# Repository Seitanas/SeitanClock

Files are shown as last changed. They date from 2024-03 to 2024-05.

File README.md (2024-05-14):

# SeitanClock
NTP clock based on ESP 12F (ESP8266)

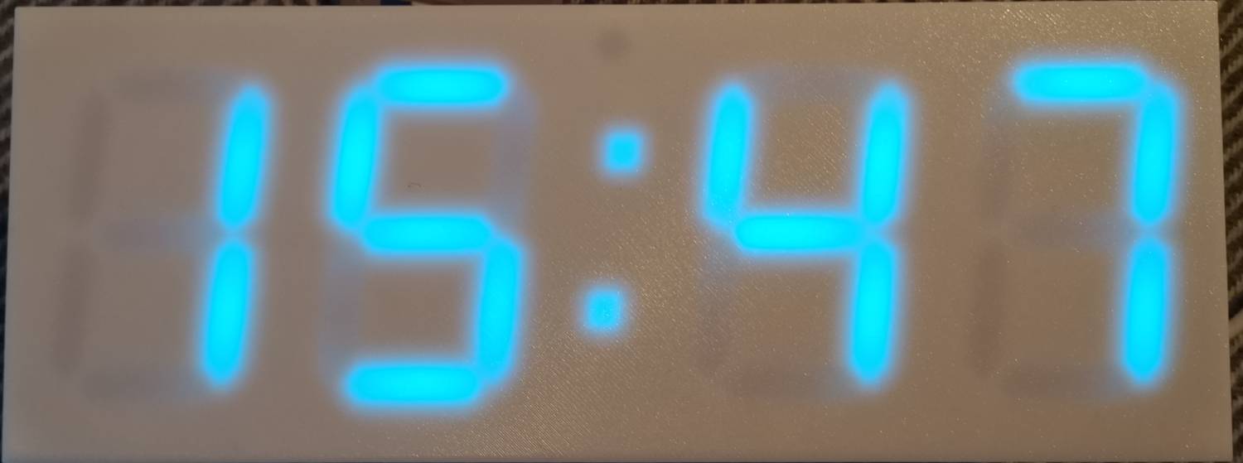
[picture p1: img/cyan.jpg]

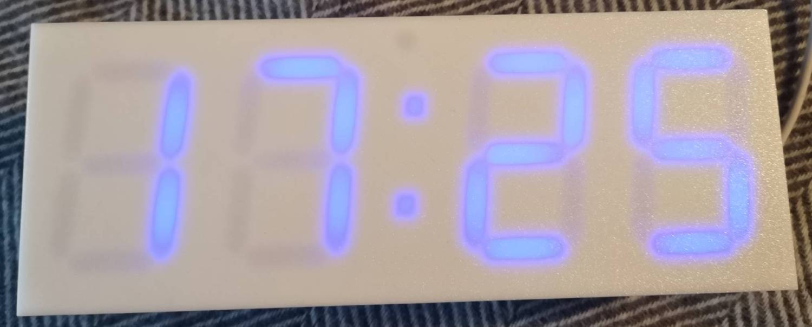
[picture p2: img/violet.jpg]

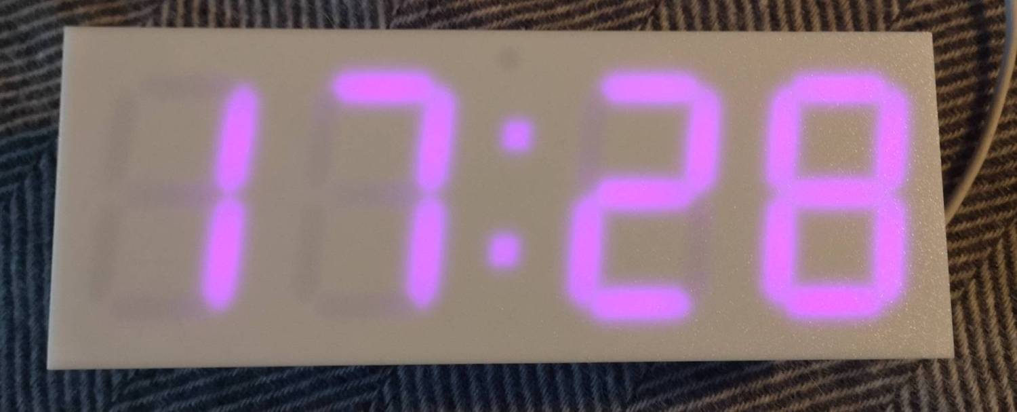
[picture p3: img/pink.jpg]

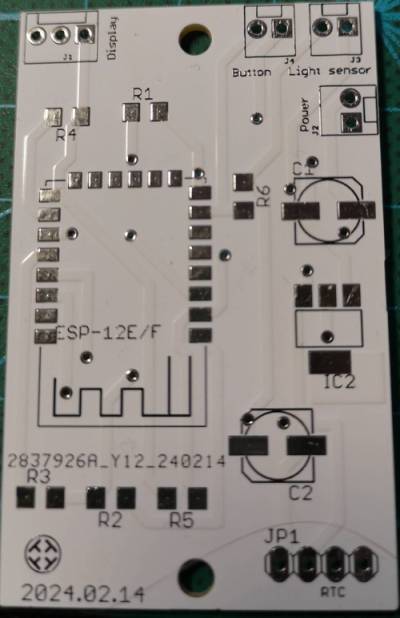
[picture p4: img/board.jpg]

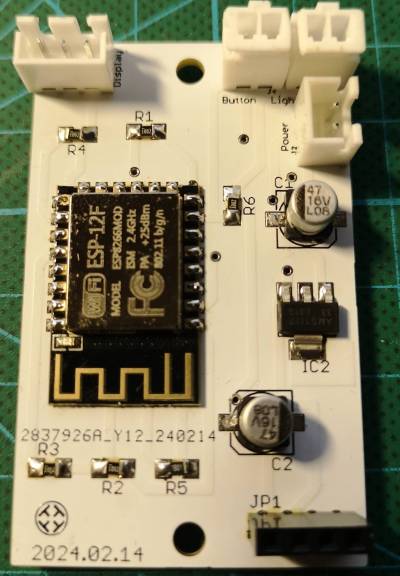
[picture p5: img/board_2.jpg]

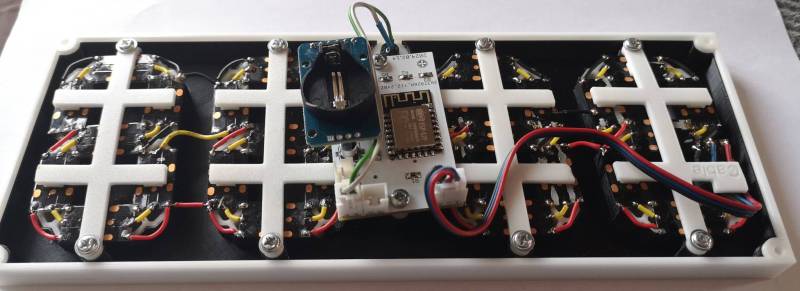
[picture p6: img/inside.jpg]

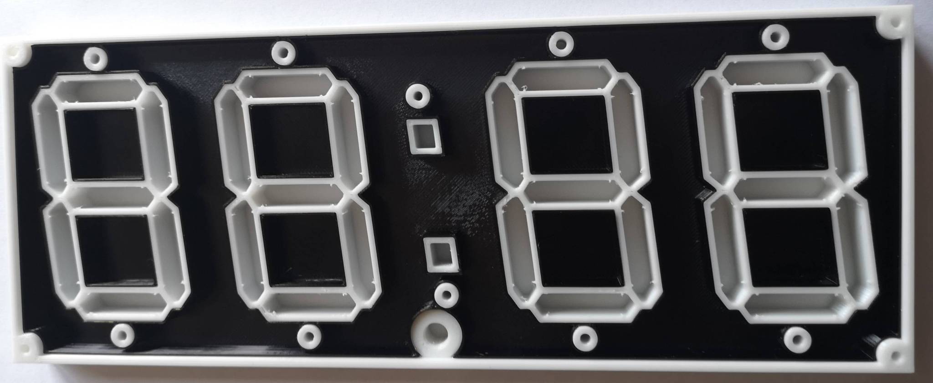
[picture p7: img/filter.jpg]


## Features
- 7 segment RGB display. Also suports stock i2c LED displays with HT16K33 driver.
- Clock synchronization via NTP over Wi-Fi.
- Updates display intensity (and color) according to day and nigh time.
- Displays date and temperature.
- Easy to use configuration portal.
- Firmware update via Wi-Fi.

## Setup mode
Clock enters setup mode at first boot (when no Wi-Fi configuration is present yet).
To enter setup mode manually, power-cycle clock while pressing the button down.
Display will show `StP` message.
In setup mode clock acts as Wi-Fi hot-spot. There will be new Wi-Fi network `SeitanClock-setup` available. Connect to it with default password `seitanclock`. Point your browser to `http://seitanclock-setup.local`. 
<u>Note</u>, that Android phones seems to lack MDNS support, so in case you are using Android phone, point your browser to IP instead: `http://192.168.4.1`. Default username for portal is `admin`, password `admin`.
Use setup portal to configure your clock. Save and reboot after.

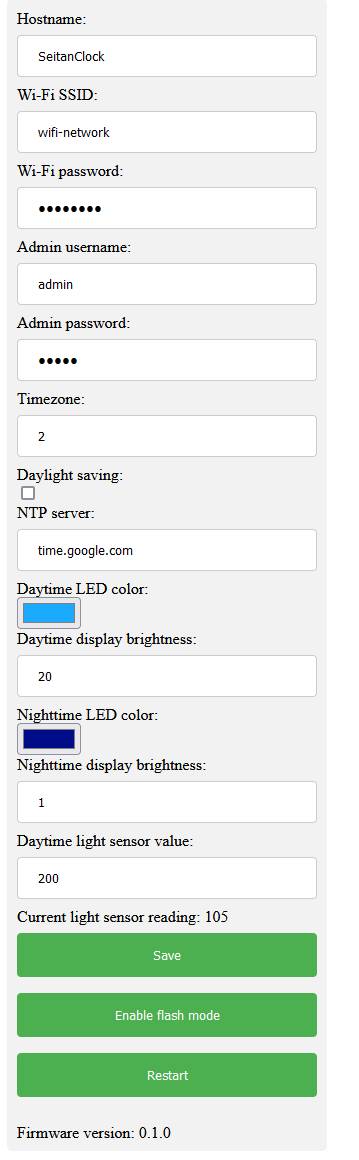
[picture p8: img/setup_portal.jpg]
Setup portal


## Flash mode
Clock has a built-in feature to update its firmware via Wi-Fi.
To get latest firmware:
- Get latest code release from https://github.com/Seitanas/SeitanClock
- Open it with Arduino IDE.
- Enter clock setup portal via `http://seitanclock.local`
- Push `Enable flash mode` button. Clock should display `FLA` message.
- Go to Arduino IDE -> Tools -> Port. Select `SeitanClock-flash.local` (or if you have changed clock host name, use `YOURHOSTNAME-flash.local`). You may need to wait for a moment for network port to appear.
<u>Note</u>, that clock and computer you are running Arduino IDE must reside in the same network segment.
- Select Sketch -> Upload.
- Wait for upgrade to finish. Clock will restart automatically. Firmware upgrade leaves clock configuration intact.

## Component list
- 1m WS2812B DC5V, 144 IP30 RGB LED tape.
- 1pc DS3231 RTC module.
- 1pc GL5506 LDR photosensitive resistor.
- 1pc ESP-12f module.
- 1pc 1.2K 1206 SMD resistor.
- 5pcs 10K 1206 SMD resistor.
- 1pcs AMS1117 (LM1117) 3.3 voltage regulator. SOT-223 package.
- 2pcs 47uF 0605 SMD electrolytic capacitor.
- 3pcs 2.54 mm pitch MOLEX 1x2 connector.
- 1pc 2.54 mm pitch MOLEX 1x3 connector.
- 1pc 2.54 mm pitch MOLEX 1x4 connector.
- 1pc 2.54 mm 1x4 female header.
- 1pc 6x6mm Square tactile switch.
- 1pc USB-C [breakout board](https://www.adafruit.com/product/4396).

Electrical wiring diagram and PCB layout is done with CadSoft Eagle. You can find them in `eagle` folder.
Each display segment contains 3xWS2812B LEDs. Dots contain 1 WS2812B LED. Assemble segments in order as displayed in `img/segment_order.jpg` file.  
3D models can be found in `stl` folder. And also on:  
[Printables](https://www.printables.com/model/792393-seitanclock-rgb-ntp-clock)  
[Thingiverse](https://www.thingiverse.com/thing:6516316)

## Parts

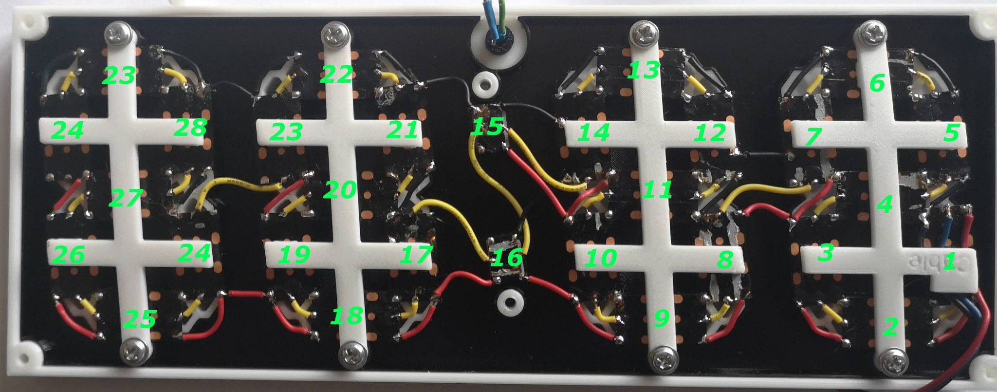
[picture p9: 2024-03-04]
img/segment_order.jpg

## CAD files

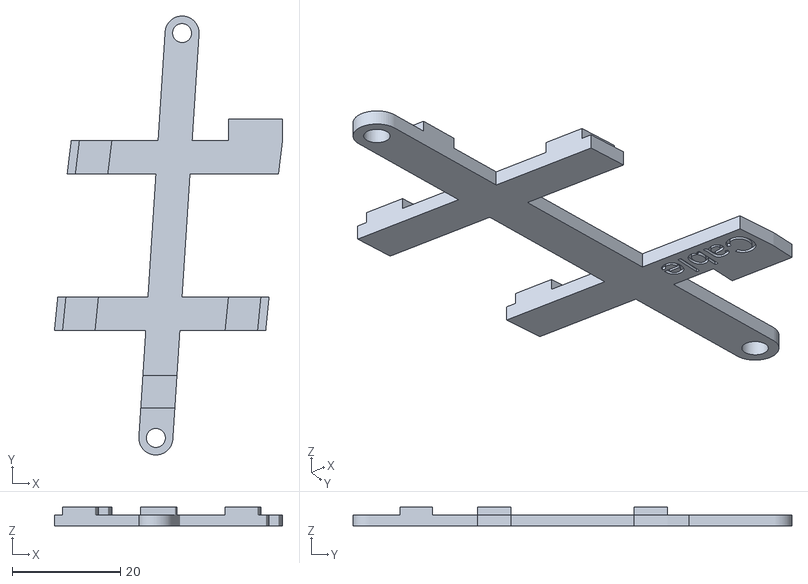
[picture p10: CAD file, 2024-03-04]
stl/FirstDisplayHolder.stl
42.1 x 81.0 x 3.50

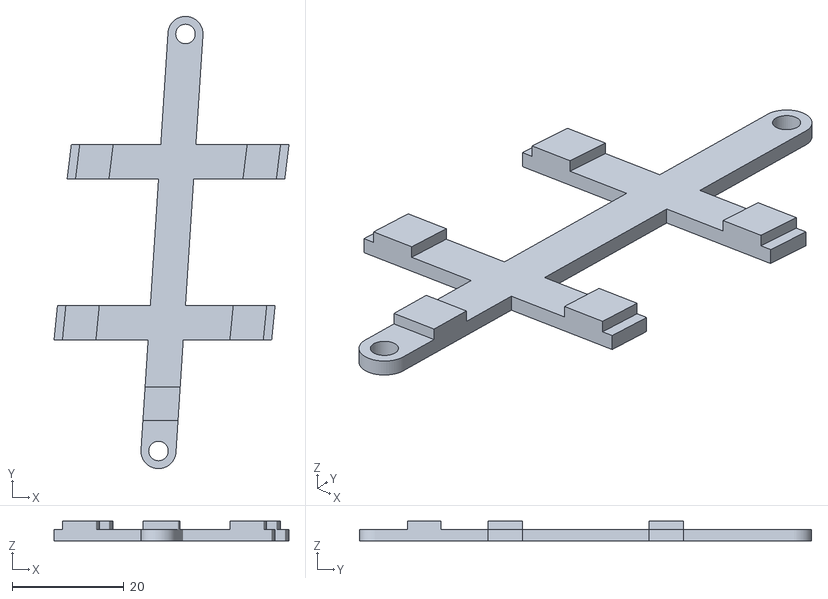
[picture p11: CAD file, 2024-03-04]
stl/DisplayHolder.stl
42.1 x 81.0 x 3.50

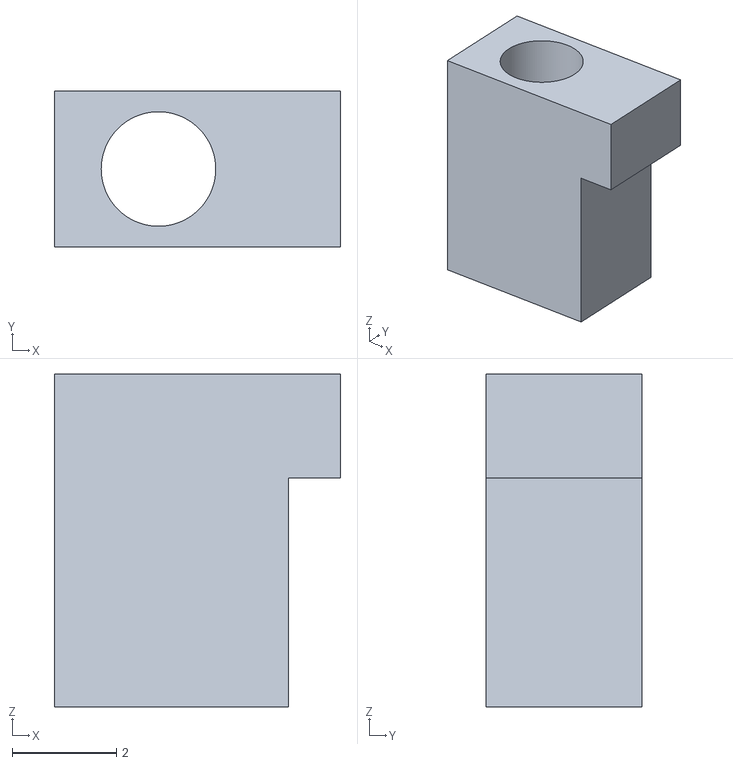
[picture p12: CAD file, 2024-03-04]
stl/UsbHolder.stl
5.50 x 3.00 x 6.40

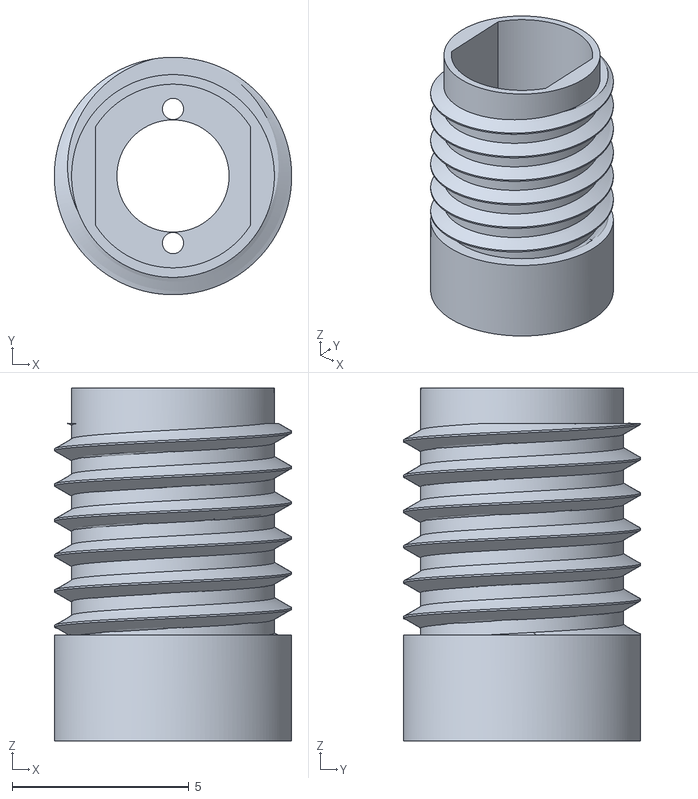
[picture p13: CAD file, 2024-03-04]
stl/SensorCasing.stl
6.72 x 6.72 x 10.0

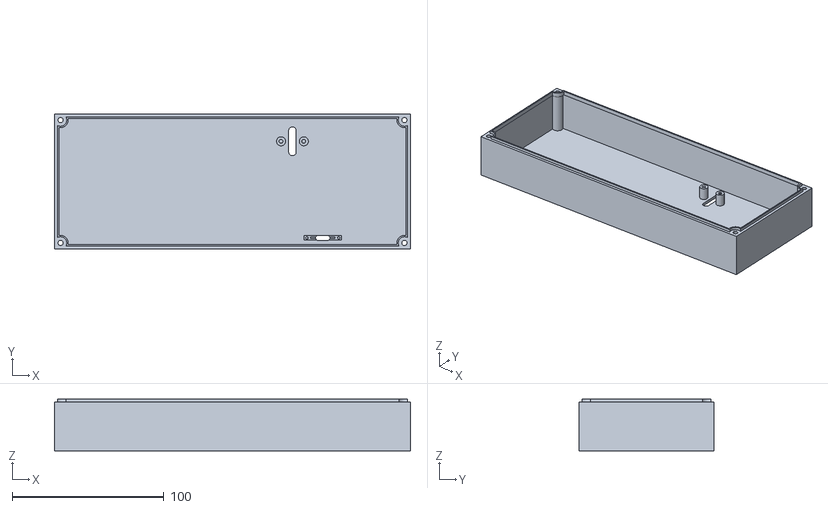
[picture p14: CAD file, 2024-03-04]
stl/Back.stl
234.7 x 89.0 x 34.0

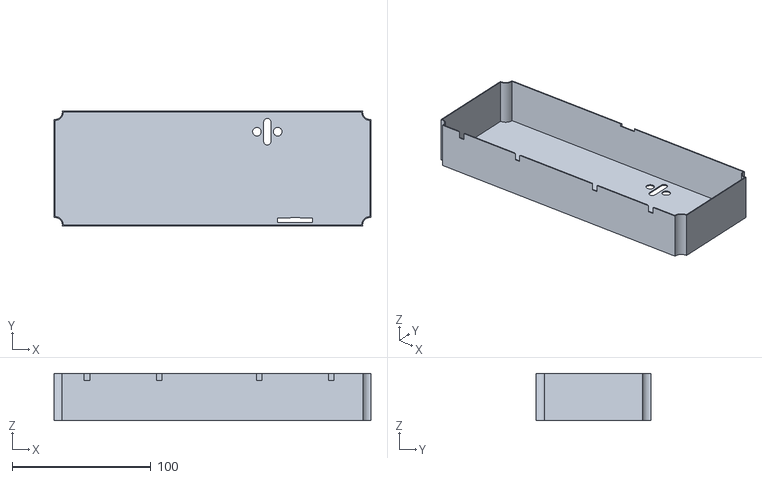
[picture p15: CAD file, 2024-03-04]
stl/FilterBack.stl
228.5 x 82.8 x 34.0

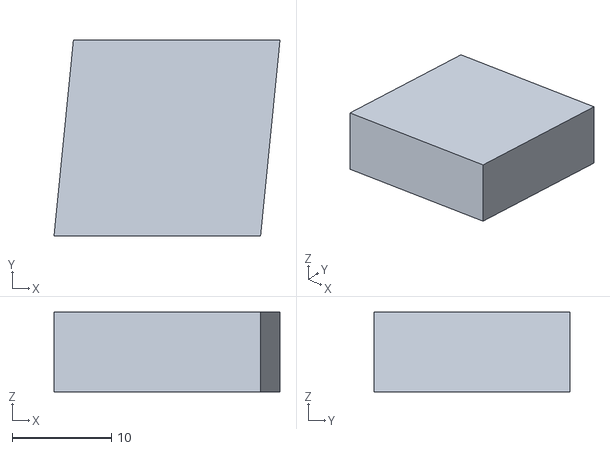
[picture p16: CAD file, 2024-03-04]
stl/FilterMiddle.stl
22.7 x 19.7 x 8.00

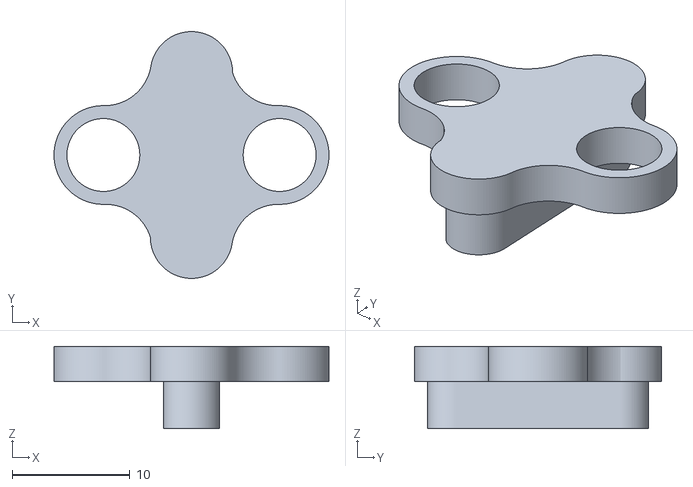
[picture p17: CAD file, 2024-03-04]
stl/Button.stl
23.4 x 21.0 x 7.00

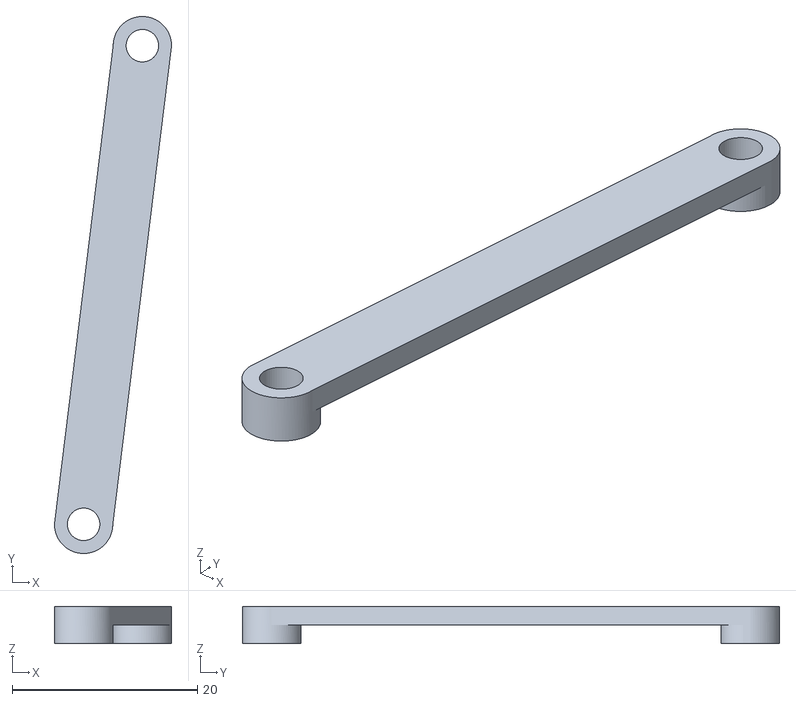
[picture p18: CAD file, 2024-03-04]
stl/DotLedHolder.stl
12.6 x 57.9 x 4.00

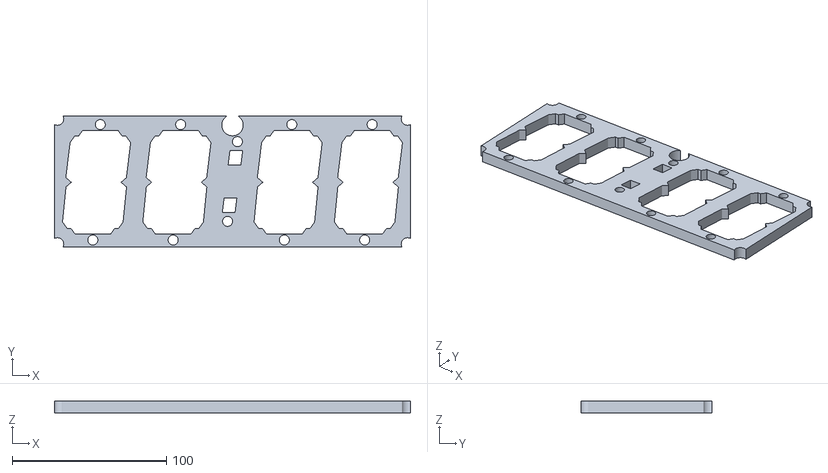
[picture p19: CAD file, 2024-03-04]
stl/FilterFront.stl
230.5 x 84.8 x 8.00

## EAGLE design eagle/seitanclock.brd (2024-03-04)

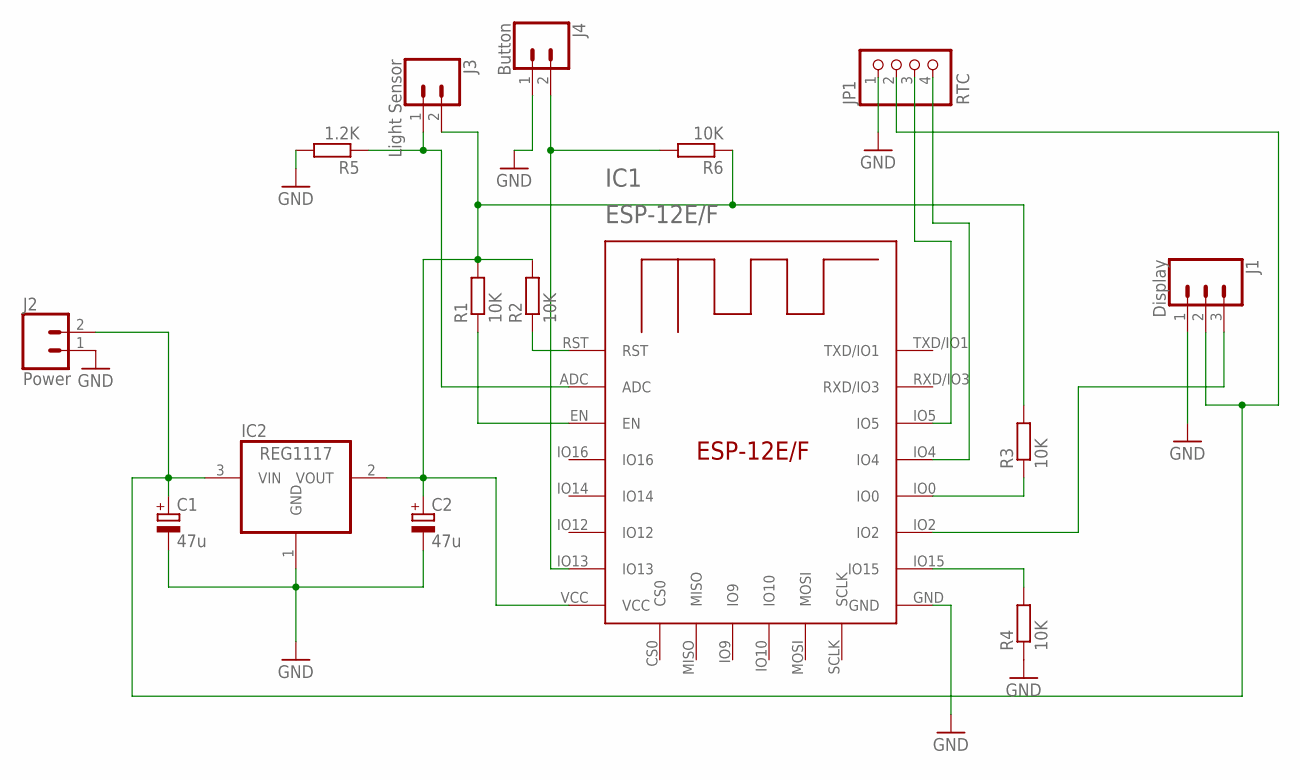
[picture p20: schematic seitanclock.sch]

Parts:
C1, C2: 47u; 153CLV-0605
IC1: ESP-12E/F; ESP-12E
IC2: REG1117; SOT223
J1: Display; MOLEX-1X3
J2: Power; MOLEX-1X2
J3: Light Sensor; MOLEX-1X2
J4: Button; MOLEX-1X2
JP1: RTC; 1X04
R1, R2, R3, R4, R6: 10K; R1206
R5: 1.2K; R1206

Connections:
GND: C1.-, C2.-, IC1.GND, IC2.1 (GND), J1.1, J2.1, J4.1, JP1.1, R4.1, R5.2
unnamed: IC1.IO5, JP1.3
unnamed: IC1.EN, R1.1
unnamed: IC1.RST, R2.1
unnamed: C2.+, IC1.VCC, IC2.2 (VOUT), J3.2, R1.2, R2.2, R3.2, R6.1
unnamed: IC1.IO15, R4.2
unnamed: IC1.IO0, R3.1
unnamed: IC1.IO4, JP1.4
unnamed: IC1.ADC, J3.1, R5.1
unnamed: IC1.IO2, J1.3
unnamed: IC1.IO13, J4.2, R6.2
unnamed: C1.+, IC2.3 (VIN), J1.2, J2.2, JP1.2

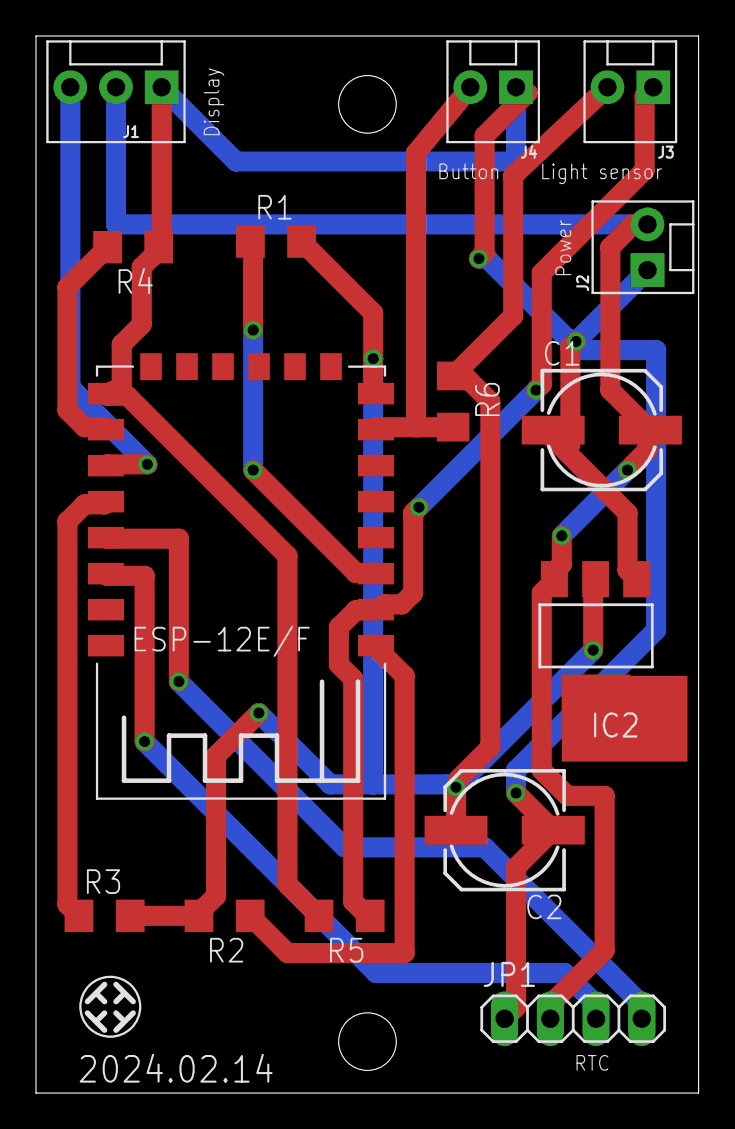
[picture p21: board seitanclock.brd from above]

Board: 2 copper layers, 36.8 x 58.7 mm, 16 parts (0 on the bottom side), 12 nets.

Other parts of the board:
U$1: SEITAN_TNAME

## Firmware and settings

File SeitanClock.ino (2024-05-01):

#include <ESP8266mDNS.h>
#include "config.h"
#include "ap.h"
#include "http_server.h"
#include "wifi.h"
#include "clock.h"
#include "display.h"
#include "light_sensor.h"


#define SETUP_PIN 13
// for how long show additional info (date/temperature) when button is pressed
#define SHOW_INFO_TIMER 2000

// should be ok for all cases
#define REFRESH_TIME 500

void setup() {
  pinMode(SETUP_PIN, INPUT); 
  Serial.begin(115200);
  clockInit();
  displayInit();
}

void loop() {
  configStructure cfg;
  rtcData tm;
  readConfig(&cfg);
  if (!digitalRead(SETUP_PIN) || cfg.wifi_ssid.length() == 0) {
    configStructure cfg; //reset config to default
    displaySetupMode(&cfg);
    startAP(&cfg);
  }
  wifiConnect(&cfg);
  delay(2000);
  MDNS.begin(cfg.host_name.c_str());
  startWebServer(&cfg);
  updateNTPTime(&cfg);
  int loop_count = 0;
  int light_avg_count = 0;
  float light_avg = 0;
  bool dot_state = false;
  int info_type = 0; // 0 = time 1 = show year 2 = show month+day 3 = show temperature
  int info_timer = 0;
  while (true) {
    handleWebServer();
    MDNS.update();
    if(!digitalRead(SETUP_PIN)) { // if setup button is pressed, display temperature, followed by date
      info_type = 1;
    }
    if (loop_count >= REFRESH_TIME) {
      loop_count = 0;
      if (dot_state) { //read rtc every second (every second time dot_state updates);
        getTime(&cfg, &tm);
      }
      dot_state = !dot_state;
      switch(info_type) {
        case 1:
          displayYear(&cfg, &tm);
          break;
        case 2:
          displayMonthDay(&cfg, &tm);
          break;
        case 3:
          displayTemperature(&cfg, &tm);
          break;
        default:
          displayTime(&cfg, &tm, dot_state);
      }
      if (light_avg_count == 10){
        light_avg_count = 0;
        if (light_avg > cfg.light_sensor_value){
          cfg.color_active = cfg.color_day;
          brightness(cfg.brightness_day);
        }
        else{
          cfg.color_active = cfg.color_night;
          brightness(cfg.brightness_night);
        }
      }
      light_avg = light_avg * light_avg_count + lightValue();
      ++light_avg_count;
      light_avg = light_avg/(light_avg_count);
    }
    if (info_timer >= SHOW_INFO_TIMER) {
      info_timer = 0;
      ++info_type;
      if (info_type > 3) {
        info_type = 0;
      }

    }
    if (info_type != 0) {
      ++info_timer;      
    }
    ++loop_count;
    delay(1);
  }
}

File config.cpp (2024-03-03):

#include "config.h"
#include <FS.h>
#include <ArduinoJson.h>

#define BUFFZIZE 512

void initializeFS() {
  bool success = SPIFFS.begin();
  if (success) {
    Serial.println("File system mounted with success");
  }
  else {
    Serial.println("Error mounting the file system");
  }
}

void readConfig(configStructure *cfg) {
  initializeFS();

  File config_file = SPIFFS.open("/config.json", "r");
  if (!config_file) {
    Serial.println("Failed to open config file for reading");
    return;
  }
  else {
    Serial.println("Reading config file");
    StaticJsonDocument<BUFFZIZE> cf;

    DeserializationError error = deserializeJson(cf, config_file);
    if (error) {
      Serial.println("Failed to read file, using default configuration");
      return;
    }
    cfg->wifi_ssid = cf["wifi_ssid"] | cfg->wifi_ssid;
    cfg->wifi_password = cf["wifi_password"] | cfg->wifi_password;
    cfg->host_name = cf["host_name"] | cfg->host_name;
    cfg->admin_username = cf["admin_username"] | cfg->admin_username;
    cfg->admin_password = cf["admin_password"] | cfg->admin_password;
    cfg->ntp_server = cf["ntp_server"] | cfg->ntp_server;
    cfg->color_day = cf["color_day"] | cfg->color_day;
    cfg->color_night = cf["color_night"] | cfg->color_night;
    cfg->brightness_day = cf["brightness_day"] | cfg->brightness_day;
    cfg->brightness_night = cf["brightness_night"] | cfg->brightness_night;
    cfg->light_sensor_value = cf["light_sensor_value"] | cfg->light_sensor_value;
    cfg->tz = cf["tz"] | cfg->tz;
    cfg->daylight_saving = cf["daylight_saving"] | cfg->daylight_saving;
    config_file.close();
  }
}

void writeConfig(configStructure *cfg) {
  File config_file = SPIFFS.open("/config.json", "w");
  if (!config_file) {
    Serial.println("Failed to open config file for writing");
    return;
  }
  else {
    Serial.println("Writing config file");
  }

  StaticJsonDocument<BUFFZIZE> cf;
  cf["wifi_ssid"] = cfg->wifi_ssid;
  cf["wifi_password"] = cfg->wifi_password;
  cf["host_name"] = cfg->host_name;
  cf["admin_username"] = cfg->admin_username;
  cf["admin_password"] = cfg->admin_password;
  cf["ntp_server"] = cfg->ntp_server;
  cf["color_day"] = cfg->color_day;
  cf["color_night"] = cfg->color_night;
  cf["brightness_day"] = cfg->brightness_day;
  cf["brightness_night"] = cfg->brightness_night;
  cf["light_sensor_value"] = cfg->light_sensor_value;
  cf["tz"] = cfg->tz;
  cf["daylight_saving"] = cfg->daylight_saving;

  if (serializeJson(cf, config_file) == 0) {
    Serial.println("Failed to write to config file");
  }
  config_file.close();
}

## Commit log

2024-03-04 SeitanClock: add documentation
    [seitanclock.brd, seitanclock.sch]
2024-03-04 SeitanClock: add 3D models
    [Back.stl, Button.stl, DisplayHolder.stl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]
2024-05-01 SeitanClock: add HT16K33 display driver

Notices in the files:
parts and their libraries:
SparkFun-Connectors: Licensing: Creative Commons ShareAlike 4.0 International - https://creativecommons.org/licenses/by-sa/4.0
